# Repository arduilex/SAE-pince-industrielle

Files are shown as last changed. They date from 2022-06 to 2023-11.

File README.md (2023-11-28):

# SAE-pince-industrielle
Instrumentation d'une pince pour un robot indutrielle Stäubli avec retour d'information sur l'état de la pince sur une IHM.

Vous pouvez lire le [Rapport](ressources/Rapport.pdf) et le [mannuel d'utilisation](ressources/manuel_utilisateur.pdf)

Ce projet a été réalisé dans le cadre d'une SAE de mon BUT GEII en première année à l'IUT de Mulhouse.

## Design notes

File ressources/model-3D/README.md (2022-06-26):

Ce dossier contient :
- le boitier, qui contient la Raspberry Pi et ses extensions (pifacecad)
- le couvercle, pour fermé le boitier 
- les boutons, qu'il faudra placer sur les 5 trous du boitier avant de poser le pifacecad

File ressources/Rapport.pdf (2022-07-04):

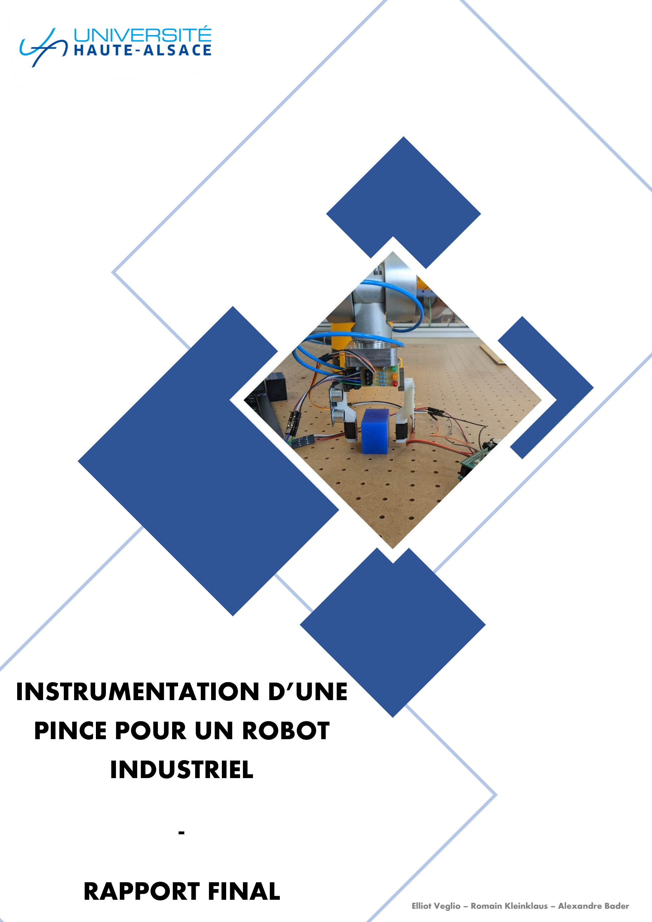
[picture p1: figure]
INSTRUMENTATION D’UNE PINCE POUR UN ROBOT INDUSTRIEL; RAPPORT FINAL

Elliot Veglio – Romain Kleinklaus – Alexandre Bader

Sommaire

### Présentation rapide de la SAE

### Contexte de la SAE

Sur un robot indus triel, la pince est un des dispositifs qui permet au robot d’interagir avec son

environnement. Grâce à une pince, le robot peut par exemple ramasser, tenir ou déplacer des objets.

Sur les robots industriels présents à l’IUT, la pince est commandée par le robot, mais il n’y a pas de

retour d’information quant à la saisie et aux collisions.

### But du travail

En tant qu’étudiant, notre but était donc d’instrumenter ces pinces pour avoir d’une part un retour sur

la saisie d’un objet et d’autre part pour détecter une collision de la pince avec un objet environnant.

Le but étant de récupérer le retour en temps réel pour améliorer la robustesse du système.

### Planning

### Planning & diagramme de Gantt théorique

Nous avons, au début de notre projet, mis en place un planning théorique que nous avons essayé de

respecter.

Nous avons retenu 11 étapes :

1. Synthèse capteurs
2. Mesures sur tables pour le capteur HC
3. Design mors
4. Tests des mors
5. Intégration sur la pince pour le capteur HC
6. Rapport de projet pour le capteur HC
7. Présentation orale pour le capteur HC
8. Mesures sur table pour le capteur ToF
9. Intégration sur la pince pour le capteur ToF
10. Rapport final du projet
11. Présentation orale finale

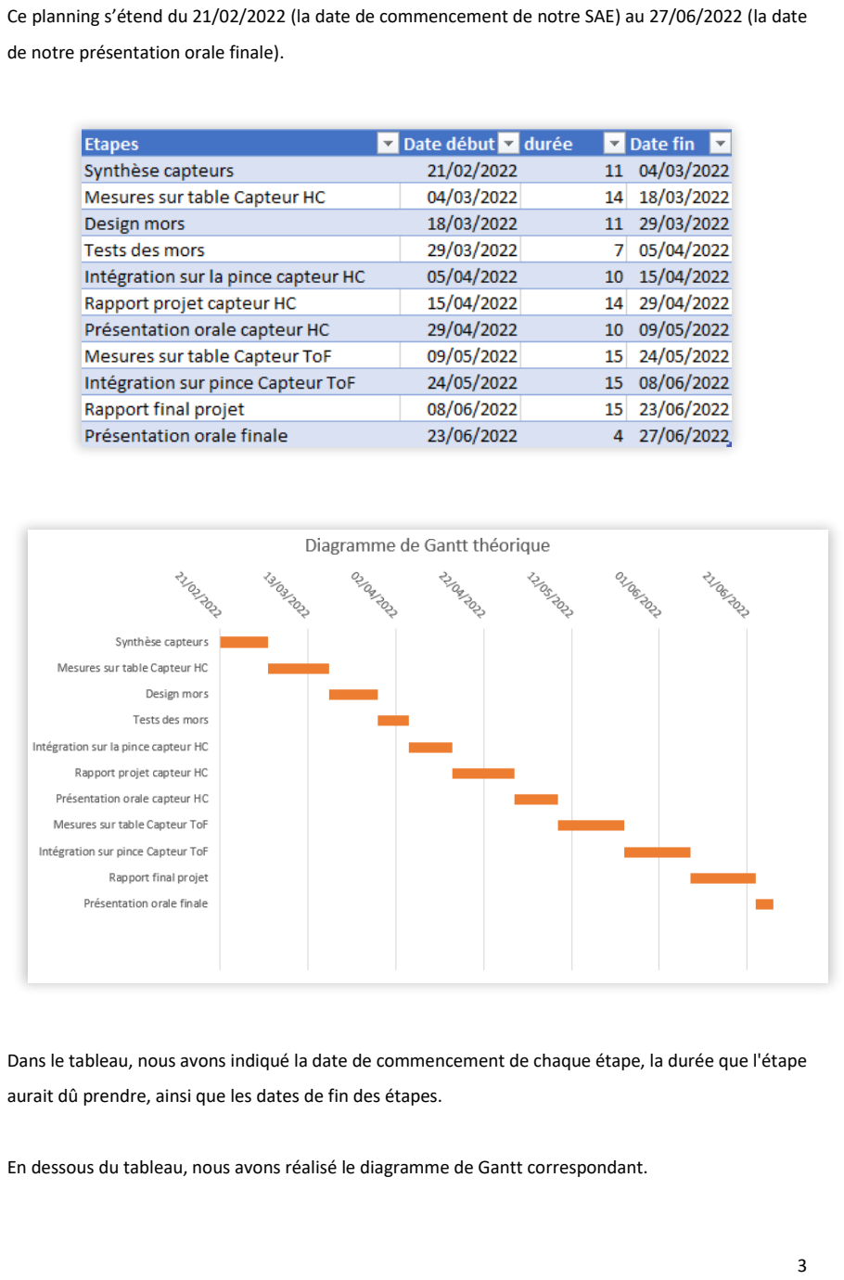
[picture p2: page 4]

Ce planning s’étend du 21/02/2022 (la date de commencement de notre SAE) au 27/06/2022 (la date

de notre présentation orale finale).

Dans le tableau, nous avons indiqué la date de commencement de chaque étape, la durée que l'étape

aurait dû prendre, ainsi que les dates de fin des étapes.

En dessous du tableau, nous avons réalisé le diagramme de Gantt correspondant.

### Planning & diagramme de Gantt réel

Au cours de la réalisation de notre projet, nous n’avons pas pu respecter complètement le planning

théorique annoncé.

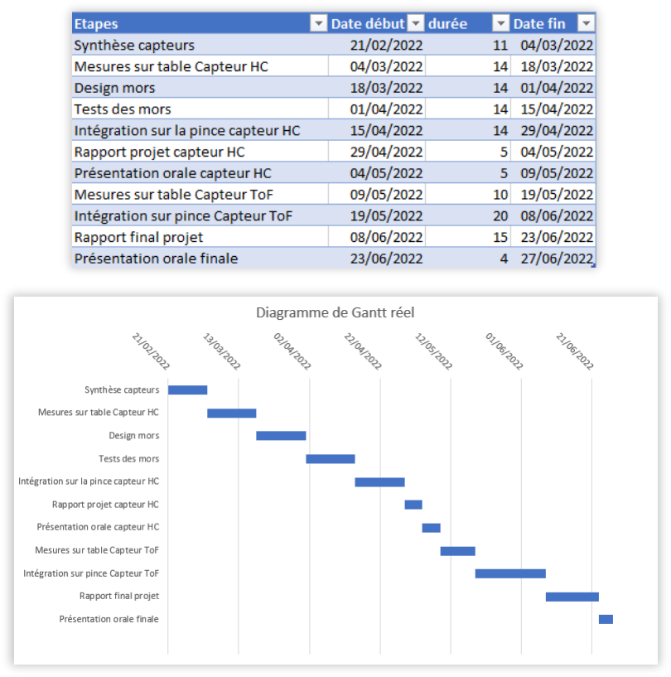
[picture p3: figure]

Nous constatons que certaines durées sont plus ou moins différentes selon les étapes dans le tableau

ci-dessus, si on les compare aux durées du tableau du planning théorique.

On remarque, entre autres, que nous avons passé deux fois moins de temps que prévu à travailler sur

le rapport de projet du capteur à ultrason et sur sa présentation orale.

### Répartition des tâches

Pour réaliser ce projet, nous nous sommes réparti les tâches à réaliser dans le but de travailler plus

efficacement.

Alexandre a travaillé principalement sur la partie programmation de notre projet, il a réalisé une

grande partie des programmes que nous utilisons.

Elliot et Romain se sont plus concentrés sur la conception des mors, du PCB et de l’intégration du

système sur la pince. Ils ont également réalisé les mesures sur table et le test des mors sur la pince

avec l’aide d’Alexandre.

Pour la réalisation de la synthèse sur les capteurs, des rapports et des présentations orales, nous avons

également travaillé à 3.

### Analyse critique de nos travaux

### Synthèse sur l’étude des capteurs

Pour avoir un retour d’information concernant la saisie ou les collisions, nous avions à disposition

plusieurs capteurs :

- Le capteur Capacitif CR30S
- Le capteur Ultrason HC-SR04
- Le capteur Photoélectrique VTF 180-2N4111
- Le capteur Laser ToF VL53L0X

Nous avons donc étudié ces 4 capteurs pour en savoir plus sur leur mode de fonctionnement et pour

apprendre à les différencier. Pour chacun d’entre eux, nous avons dû expliquer dans un rapport de

synthèse :

- Principe de fonctionnement
- Gamme de mesure, précision, fréquence
- Identifier le type de sortie
- Comment était-il alimenté et comment communiquer avec lui

- Enfin, quels choix étaient les plus optimaux pour l’intégrer sur la pince

Nous allons donc vous parler de ce que nous avons retenu de cette étude.

Concernant le capteur laser ToF, celui-ci peut être alimenté sous une tension comprise entre de 2.6V

et 3.5V ce qui est compatible avec les GPIO de la Raspberry Pi de 3.3V. Il peut ainsi être commandé et

branché directement depuis la Raspberry Pi, ce qui facilite grandement son installation sur la pince. De

plus, sa gamme de mesure est cohérente avec les distances que nous voulons mesurer. Ce capteur

peut donc être utilisé dans le cadre de l’instrumentalisation d’une pince industrielle.

Le capteur capacitif CR30S peut être utilisé pour s’arrêter avec une grande fiabilité devant un objet, ou

encore d’envoyer un signal de confirmation de fermeture de la pince. Malheureusement, sa tension

d’alimentation étant supérieur à 10V, son utilisation sur Raspberry pi n’est pas possible sans l’aide

d’une alimentation externe supplémentaire, car le Raspberry ne peut fournir que 5V au maximum.

Le capteur à ultrasons HC-SR04 est un capteur très polyvalent, sa petite taille, sa gamme de mesure

large qui reste précise de 3cm à 400cm, sa facilité d’utilisation et sa tension d’utilisation de 5V qui est

compatible avec la Raspberry Pi le rend très adapté dans le cadre de notre SAE.

Le capteur Photoélectrique VTF 180-2N41112, pourrait être utilisé avec nos mors afin de détecter la

présence des pièces près de la pince pour faciliter la manipulation de la pince ou encore éviter les

collisions. Cependant, la tension d’alimentation de ce capteur, qui est de 10V DC à 30V DC est trop

grande pour pouvoir être exploitée avec un Raspberry Pi sans l’aide d’une alimentation externe, car

ses pins ne délivrent qu’une tension de 3,3V ou 5V maximum.

Conclusion :

Parmi tous les capteurs que nous avons étudiés, le capteur laser ToF VL53L0X ainsi que le capteur à

ultrasons HC-SR04 sont, selon nous, les plus faciles et pratiques à utiliser avec un Raspberry Pi. Il n’est

cependant pas impossible d’utiliser les autres capteurs, à condition d’utiliser une alimentation externe

pour compenser la limite de 5V délivrés par la Raspberry Pi.

### Mesures sur table

Nous avons tout d’abord effectué plusieurs mesures de distances sur table, avec différents types

d’objets, pour tester les limites réelles du capteur. Ces tests ont pour but d’évaluer la précision de nos

mesures en fonction de différentes conditions. Pour mieux présenter nos résultats, nous avons classé

nos mesures en fonction des critères suivants :

- La matière de l’objet
- La couleur de l’objet
- L’orientation de l’objet
- La taille de l’objet

La matière de l’objet

Pour déterminer si la matière de l’objet a un impact sur la précision de nos mesures, nous avons décidé

de prendre plusieurs objets avec des matières différentes, à savoir : du plastique, du carton, du métal,

du plexiglas et du verre. Nous avons ensuite fait une série de mesures sur plusieurs distances.

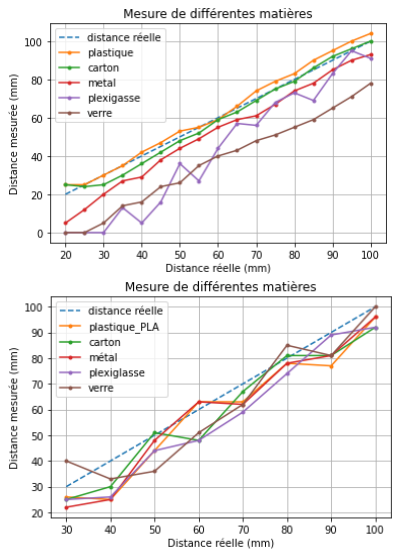
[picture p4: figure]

Voici les résultats que nous avons obtenus :

Capteur laser

Capteur à

ultrasons

Si l'on observe le graph du capteur laser, on s'aperçoit que les matières qui diffractent la lumière ou

laissent passer la lumière (le verre et le plexiglas) ont tendance à s'éloigner de la distance réelle. Tandis

que les matières qui diffusent la lumière, telles que le plastique ou le carton, sont plutôt proche de la

réalité.

On peut donc en conclure que le capteur laser est inutilisable sur des objets qui diffracte la lumière

tels que des objets en verre ou en plexiglas. Cela ne nous pose pas de problème, car notre capteur ToF

va être utilisé face à une surface en plastique PLA.

Concernant le capteur à ultrasons, on ne remarque pas de grandes différences entre les courbes, on

en déduit que la matière importe peu pour la qualité des mesures de ce capteur.

La couleur de l’objet

Pour déterminer si la couleur de l’objet avait un impact sur la précision de nos mesures, nous avons

décidé de prendre un Rubik’s Cube pour faire des mesures avec chacune de ses faces. Sachant que le

Rubik’s Cube est en plastique (l’une des matières les plus fidèles comme montré précédemment)

seules les différentes couleurs rentrent en jeu.

Voici les résultats que nous avons obtenus :

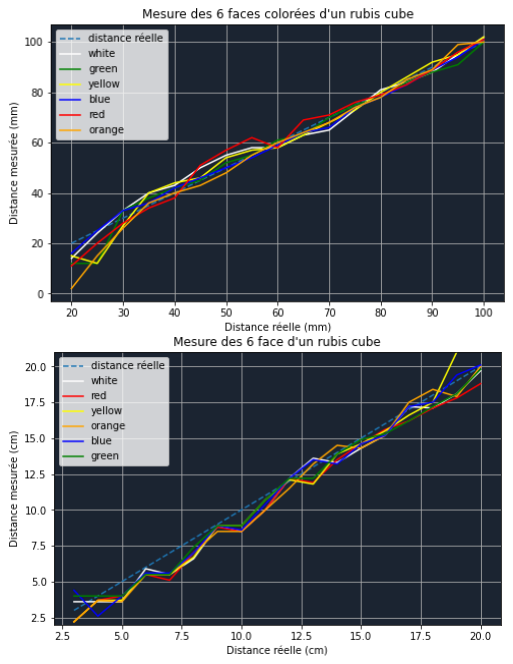
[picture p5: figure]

Capteur laser

Capteur à

ultrasons

D’après les graphes que nous avons obtenu pour le capteur laser et le capteur à ultrasons, on remarque

qu’il n’y a aucune une différence et qu’elles convergent toutes vers la distance réelle.

Ainsi, on peut dire que la couleur de l’objet n’influe pas sur la précision de nos mesures que ce soit

avec le capteur laser ou le capteur à ultrasons.

L’orientation de l’objet

Pour déterminer si l’orientation de l’objet a un impact sur la précision de nos mesures, nous avons

décidé de prendre une plaque en plastique pour faire des mesures en changeant l’orientation du

capteur en fonction de la plaque.

Voici les résultats que nous avons obtenus :

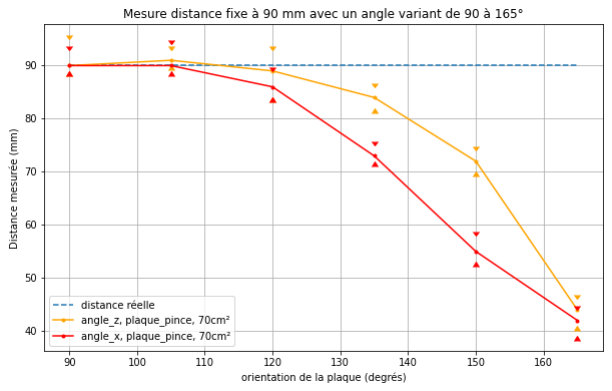
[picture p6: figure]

Capteur laser

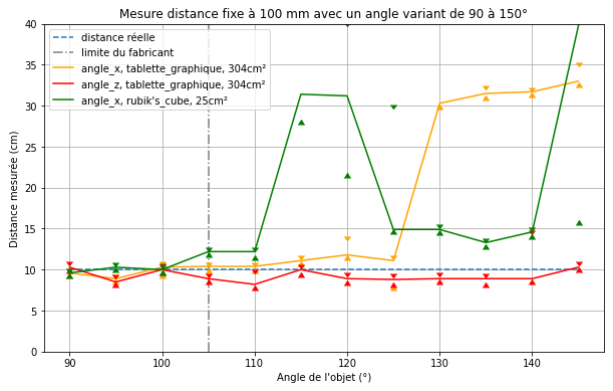
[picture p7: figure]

Capteur à

ultrasons

D’après le graphe que nous avons obtenu, on remarque que lorsqu’on modifie l’angle (que ce soit de

façon horizontale ou verticale), plus l’orientation de la plaque s’éloigne de 90 degrés, plus la distance mesurée est faussée. À partir de 110° les mesures sont inexploitables. Si l’on souhaite obtenir une

mesure précise, il faut que l’objet soit positionné de façon perpendiculaire par rapport au capteur

laser.

La taille de l’objet

Enfin, concernant la taille de l’objet, nous avons décidé de prendre une feuille, que nous avons pliée

en 2 entre chaque mesure. Ainsi, nous avons divisé par 2 la surface de la feuille (et donc la taille de

l’objet) pour chacune des mesures prises par le capteur

Voici les résultats que nous avons obtenus :

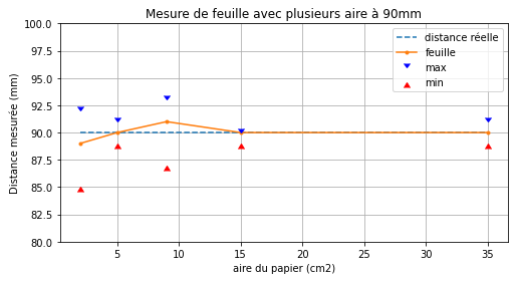
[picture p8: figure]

Le graphe que nous avons obtenu, représentant la mesure de la distance en fonction de la surface de

la feuille, est plus ou moins une droite. Ceci signifie que la taille d'un objet n'a pas d'incidence sur les

mesures que prend le capteur ToF.

Capteur laser

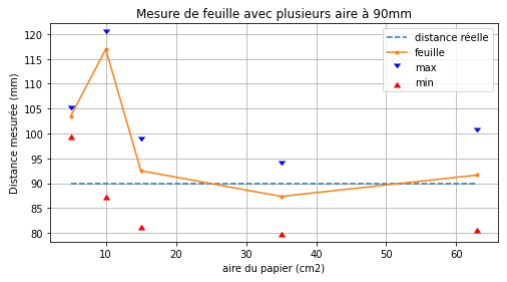
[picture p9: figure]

Capteur à

ultrason

Nous avions également fait les mêmes mesures avec le capteur HC, on constate toute de suite qu’avec

ce capteur, une surface trop petite à des conséquence néfaste sur la qualité de la mesure. A partir de

15cm² les mesures sont exploitables, mais pas en dessous.

### Réalisation des mors

Afin d’intégrer le capteur sur les mors il nous faut designer des mors compatible avec les 2 capteurs,

ce qui est réalisable, car les 2 capteurs ne demandent que 4 pins de connexion. L'emplacement des

pins va être utilisé comme support pour maintenir le capteur en place.

Pour concevoir les mors que nous devions intégrer sur la pince, nous avons utilisé le logiciel de

modélisation Autodesk Fusion 360.

Nous nous sommes basés sur ces dimensions imposées :

- Taille minimum entre les mors pince fermé de 2,5cm.
- Surface de contact avec les objets pour les mors (1,5*2cm).
- Taille minimum des câbles entre le Raspberry et la pince 30 cm.

Lors de la conception de nos mors, nous avons fait attention à bien réfléchir à l’intégration du capteur

sur ceux-ci. Nous avons décidé de fixer le capteur sur le haut du mors droit, et d’insérer une plaque sur

le mors gauche, le tout créé par une imprimante 3D. Puisque nous avons décidé d’implémenter le PCB

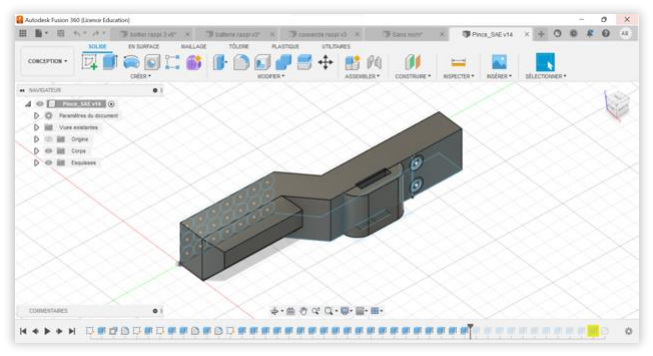
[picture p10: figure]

sur la pince, nous n’avons pas besoin de modifier nos mors pour y intégrer le PCB. Le principe de

fonctionnement est simple, le capteur à ultrasons ou laser va envoyer des ondes sonores ou

électromagnétiques en direction de la plaque en plastique. Les ondes vont rebondir sur cette dernière

pour ensuite se propager dans la direction inverse, vers le capteur. Le temps de vol de l’onde entre son

émission et sa réception est utilisé pour calculer la distance entre le capteur et la plaque.

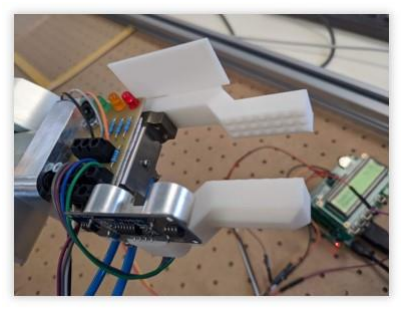
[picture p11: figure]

Réalisation du PCB.

Nous avons également réalisé un PCB sur Kiccad pour notre système. Ce PCB permet de réaliser la

liaison électrique entre le capteur et le Raspberry Pi. Nous avons placé des borniers pour les liaisons

électriques, des résistances et il y a également 3 LEDs rouge, orange et verte respectivement qui

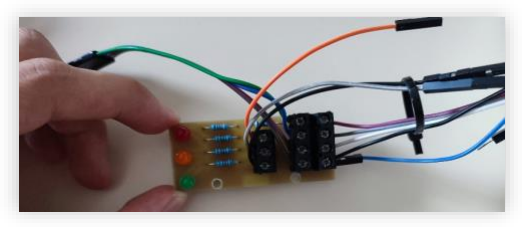
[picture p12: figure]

permettent d’indiquer l’état de la pince.

Notre PCB est assez petit, car nous l’intégrons sur la

pince directement et la place disponible est limitée.

### Réalisation du boîtier

Le boîtier permet de protéger le circuit de la Raspberry Pi et ses modules de l’extérieur. Le but étant

de pouvoir fixer le boîtier sur le bras du robot et ainsi limiter au maximum les longs câbles qui

parcourent le bras robotique pour arriver sur la table, car cela peut limiter les mouvements du robot.

Construction

La base du boitier doit pouvoir maintenir fermement la Raspberry Pi. Pour cela, nous utilisons les 4

trous disponibles sur cette dernière. On trouve facilement sur internet les dimensions précises de la

Raspberry Pi, ainsi la modélisation correspond parfaitement à la réalité. Pour se fixer sur ces trous,

nous utilisons 4 trous taraudés pouvant accueillir une vis M2.5.

Un trou est placé sur le bas-côté pour faire entrer le câble micro USB d’alimentation.

Le couvercle du boitier est imprimé à part. Il comporte 2 rectangles vide : l’un pour faire ressortir

l’écran LCD, l’autre pour sortir les 12 câbles de breadboard connecté à la Raspberry Pi.

Pour maintenir ces câbles, nous utilisons de la colle chaude.

Sur 2 faces du boitier, 9 trous ont été ajouter afin de créer une ventilation, indispensable pour le micro-

ordinateur qui dégage une chaleur non négligeable.

Pour alimenter la Raspberry Pi tout en restant indépendant du réseau électrique sur secteur, nous

avons opté pour une batterie externe de 20 000 mAh ainsi qu’un câble micro USB coudé de 25cm pour

une meilleure ergonomie.

Problèmes rencontrés

Le bouton/joystick est très ergonomique à utiliser, nous avons essayé de l’utiliser avec le boitier, mais

malheureusement il est très difficile à utiliser une fois dans le boitier, alors que les boutons ont juste

besoin d’une rallonge. Nous avons donc abandonné le bouton/joystick pour se concentrer sur les 5

boutons de l’avant.

Les encoches du couvercle nous ont posé beaucoup de problèmes. En effet, ils doivent être

parfaitement identique aux encoches femelles du boitier, mais avec une échelle inférieure de l’ordre

du 10ᵉ de millimètre pour pouvoir s’emboiter.

L’emplacement des trous sur le boitier pour communiquer avec les boutons nous a valu plusieurs ratés

de positionnement. Nous ne pouvions pas mesurer avec précision à quelles hauteurs ils étaient placés,

car la structure des 2 modules n’est pas fixe. De plus, toute la modélisation devait avoir comme

référence les 4 trous de fixation de la Raspberry Pi.

Boitier dans sa version finale contenant la Raspberry Pi et ses modules

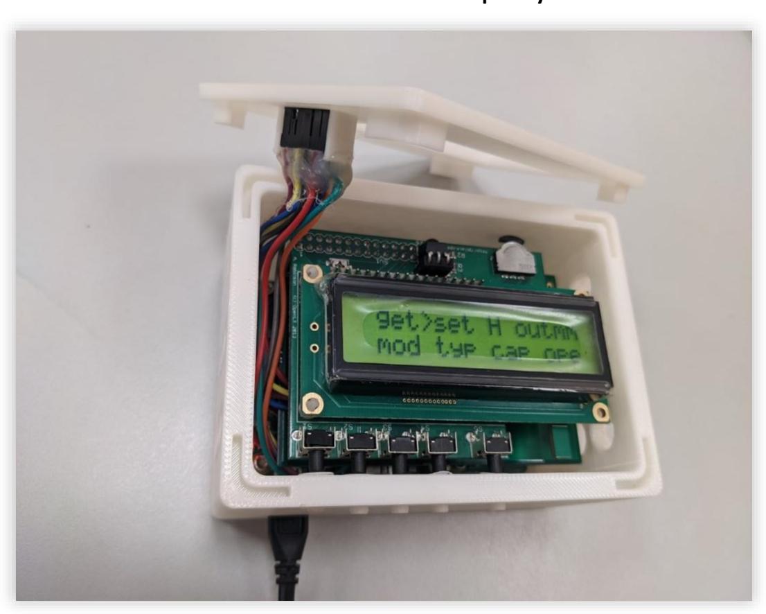
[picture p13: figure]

### Réalisation Programme

L’entièreté du programme à été développé en Python 3.9. Le programme principale (voir annexe)

repose sur des fonctions asynchrones. Elles permettent de s’exécuter en même temps, par

concurrence, c’est-à-dire lorsque qu’une fonction ne fait rien (pause await) une autre s’exécute.

Toutes ces fonctions en concurrence vont appeler des fonctions qui se trouve dans un autre fichier :

appli.py. Ce fichier contient une classe Python qui gère l’entièreté de l’interface et du système de

mesure. Le principe de classe est indispensable ici car il permet de se passer des variables globales en

utilisant self (un objet contenant toutes les variables et fonctions créés dans la classe) dans chaque

paramètre de fonction (appelé méthode dans une classe).

Sur la partie appli.py on peut voir le fonctionnement de la méthode d’initialisation, elle va rechercher

des fichiers texte qui contiennent des valeurs sauvegarder de la dernière exécution du programme. La détection de l’état de la pince se fait en fonction de la distance mesurer par le capteur. Cette mesure

est appelée via une fonction qui se trouve dans un autre fichier. Soit le programme va accéder au

fichier HCS404.py si le capteur utilisé est l’ultrason, soit dans le fichier VL53L0X.py si le capteur utilisé

est le laser.

Nous avons rencontré beaucoup de problème au cours du développement, notamment sur les

fonctions asynchrones et les classes qui étaient des nouvelles notions à assimilé pour nous. Alexandre

nous à beaucoup aidé grâce à ses connaissances avancées dans le langage Python.

### Intégration du système sur la pince

Après avoir conçu notre système, nous allons maintenant parler de l’intégration de celui-ci sur la pince.

Tout d’abord, pour intégrer les 2 mors imprimés en 3D sur la pince, nous avons utilisé les 4 trous

taraudés de chaque côté de la pince pour les fixer sur celle-ci.

Nous avons également réalisé le circuit électrique comprenant la Raspberry Pi, son alimentation, un

optocoupleur et le capteur.

Grâce à l’aide d’un optocoupleur, nous pouvons envoyer un signal de 24V aux entrées TOR, à l’aide du

signal sortant de la Raspberry Pi de 3.3V.

L’optocoupleur peut rendre des circuits électriques indépendants. En effet, l’optocoupleur est un

composant électronique permettant de transmettre un signal d’un circuit électrique à un autre sans

être relié électriquement avec lui permettant de garantir l’isolation galvanique. Il est formé d’une LED

infrarouge et d’un phototransistor.

Lorsqu’un courant électrique passe dans la LED, elle va émettre un signal infrarouge dans un boîtier

hermétique à la lumière. Le phototransistor va ensuite capter la lumière infrarouge et devenir passant

pour transmettre le courant électrique.

Ci-dessous le résultat final de notre système fonctionnel. Une batterie externe de 20000mAh est placée

sous le boitier

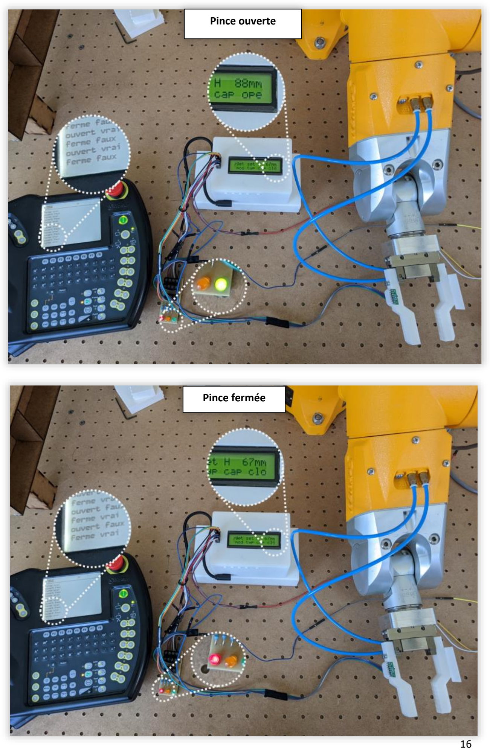
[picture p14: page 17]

Pince ouverte

Pince fermée

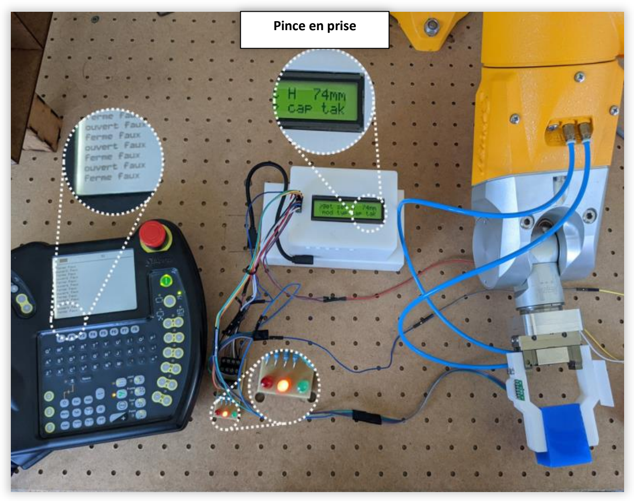
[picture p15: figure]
Pince en prise

Lors de nos tests en condition réels sur le bras robotique, nous pouvions choisir la précision du capteur

ToF, il en possède 4 : speed, good, better et best. Le mode speed est le moins précis des 4, mais à

l’inverse du mode best, il est le plus rapide avec un taux de rafraîchissement de 50 mesures / seconde

contre 30/s en good, 15/s en better et 5/s en best.

Tous ces modes sont implémentés dans le module open source du capteur ToF que nous avons

récupéré sur GitHub. (https://github.com/pimoroni/VL53L0X-python) Pour avoir une similarité avec le capteur ultrason, nous avons créé une classe

Python qui possède la même gestion de ces 4 modes.

Pour revenir à nos tests réels, il est clair qu’en choisissant le mode best, on obtient de meilleurs

résultats dans le maintien d’un état détecter de la pince au cours du temps. Si on passe à des modes

moins précis, il en résulte des fluctuations de l’état (par exemple la pince est ouverte et l’état retranscrit varie entre ouvert et en prise). Pour essayer de comprendre pourquoi ce phénomène ce

produit, nous avons réalisé des mesures semblables à un oscillogramme.

La courbe bleue représente les mesures du capteur au cours du temps, en orange la courbe est la

retranscription de l’état de la pince au cours du temps. Les 3 états sont facilement lisibles : ouvert =

85mm, en prise=79mm, fermé=74mm.

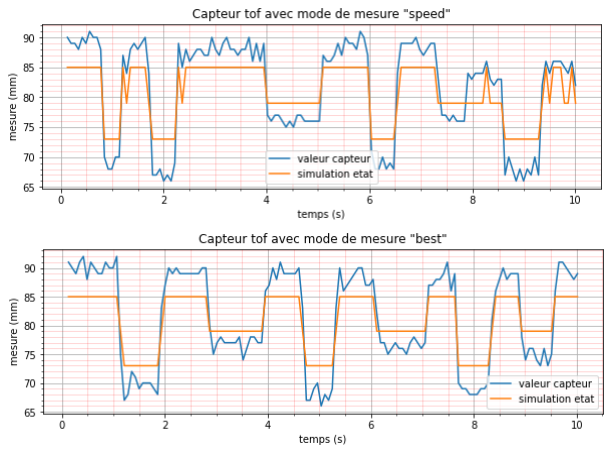
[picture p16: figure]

On remarque tout de suite que pour le même réglage des valeurs limite, le mode best est beaucoup

plus précis et comporte moins d’erreur. Le même phénomène se produit avec le capteur ultrason.

Comme nous l’avons vu le mode best comporte moins d’erreur, mais il permet que de fournir 5

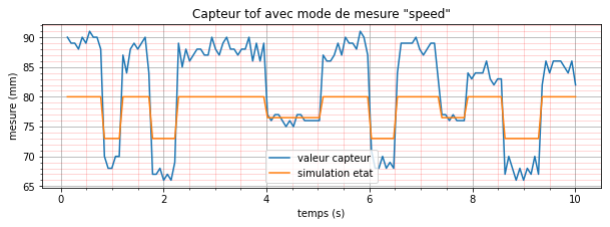
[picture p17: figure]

mesures par secondes. La première solution qui vient à l’esprit serait d’utiliser un compromis entre

speed et best comme good ou better, mais il existe une 2eme solution qui consiste à modifier les

valeurs limites d’état.

En changeant la valeur max de 85mm à 80mm, on obtient un signal aussi propre que celui du mode

best. Ainsi, nous pouvons allier la haute fréquence de mesure de ce mode sans obtenir d’erreur.

Néanmoins, une nouvelle contrainte est créée : l’état en prise, devient très serré entre le max et le

min. Les objets pris par la pince doivent alors obligatoirement être d’une taille proche de 77mm.

On peut donc définir le théorème suivant : plus les valeurs limites d’états sont éloignées, plus la taille

de l’objet entre les mors peut varier. La réciproque est aussi vraie.

### Synthèse

Au cours de cette année, nous avons appris à instrumentaliser une pince pour améliorer sa robustesse.

L’amélioration majeure apportée est un retour d’information sur l’état de la pince via un capteur de

distance. Le retour d’information se faisant au travers de 3 LEDs, de l’écran LCD mais aussi sur la

télécommande du robot. Pour intégrer le capteur, nous avons créé une nouvelle version des mors.

Nous avons découvert, pour certain, la modélisation 3D ainsi que l’impression 3D. Le système est

embarqué via un Raspberry Pi et le module PifaceCad comportant un écran LCD et des boutons. Nous

avons appris à nous servir de Linux et enrichi nos connaissances en Python.

Nous avons réalisé le projet sur une période de 126 jours et nous avons pu respecter les délais pour

chaque tâche demandée.

Tableau des coûts du projet :

Objet | Coût
Raspberry Pi + PifaceCad | 56,88€ (TTC)
Composants électronique (LED, résistances, borniers, câbles) | 3,00€ (TTC)
Capteur ToF | 16,00€ (TTC)
Capteur HC | 5,00€ (TTC)
Plastique imprimante 3D | 10,00€ (TTC)

Outils (pince coupante, tournevis, etc…) | 20,00€ (TTC)
TOTAL : | 110,88€ (TTC)

### Perspective pour les suites éventuelles

Après la réalisation de ce projet, notre système permet l’instrumentalisation d’une pince, ce qui nous

ouvre la voie à de nombreuses perspectives.

Tout d’abord, on pourrait améliorer la stabilité du capteur sur les mors, ainsi que celle de la plaque

fixée sur un des mors pour ainsi améliorer l’exactitude des mesures et du retour d’information

concernant la prise d’objet. On envisagerait également d’améliorer le circuit électrique reliant le

système, en implémentant, entre autres, l’optocoupleur dans le circuit et en travaillant sur la gestion

des câbles pour obtenir un système plus compact et mieux rangé.

En effet, ce système pourra améliorer la prise d’objet de la pince, tout en implémentant une détection

de collisions.

Du fait de cette instrumentalisation de la pince, on peut imaginer que l’on pourra plus facilement

résoudre certains problèmes, dont celui des Tours d'Hanoï, qui requiert une précision accrue de la

prise d’objet faite par la pince.

On pourra également espérer créer l’automatisation de certaines tâches grâce au système à l’aide de

la création de programmes supplémentaires.

### Annexes

Organigramme de l’application en Python :

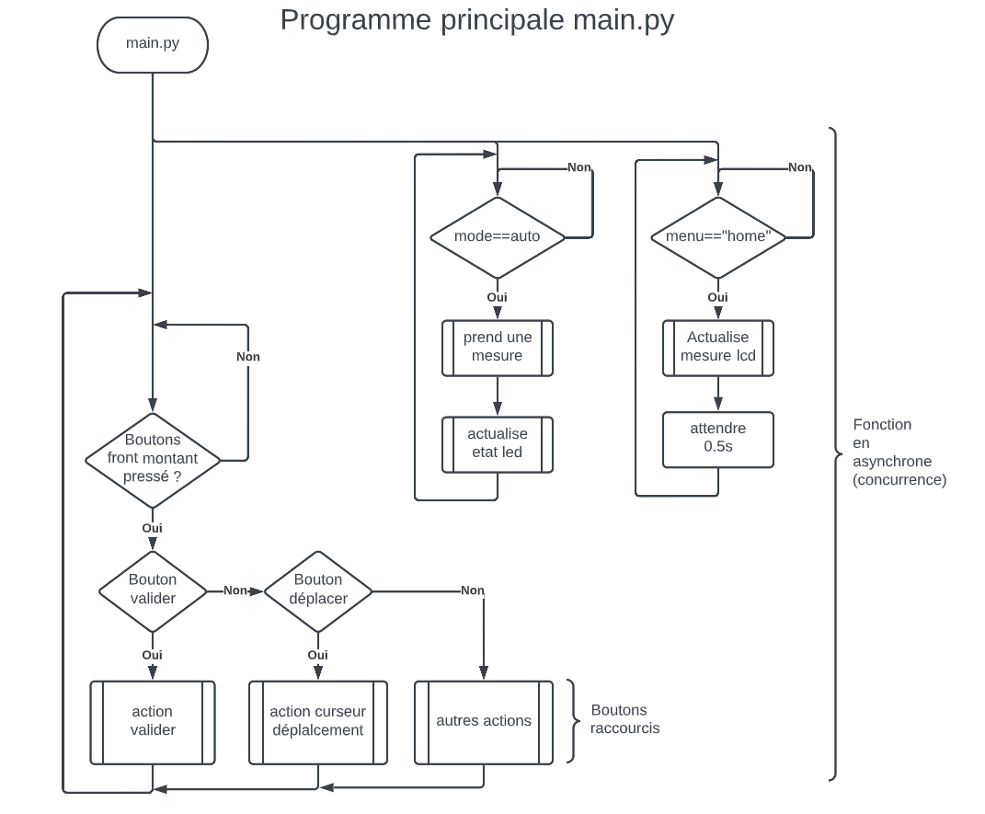
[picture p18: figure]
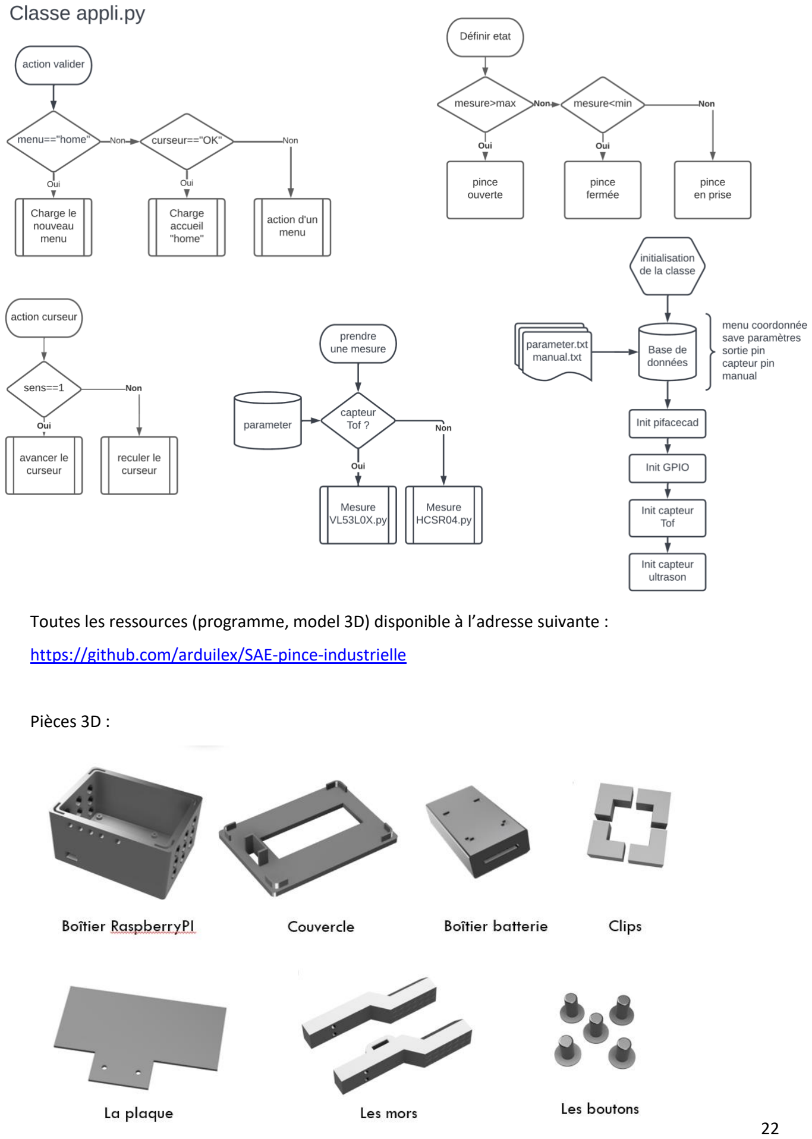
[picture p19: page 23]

Toutes les ressources (programme, model 3D) disponible à l’adresse suivante :

https://github.com/arduilex/SAE-pince-industrielle

Pièces 3D :

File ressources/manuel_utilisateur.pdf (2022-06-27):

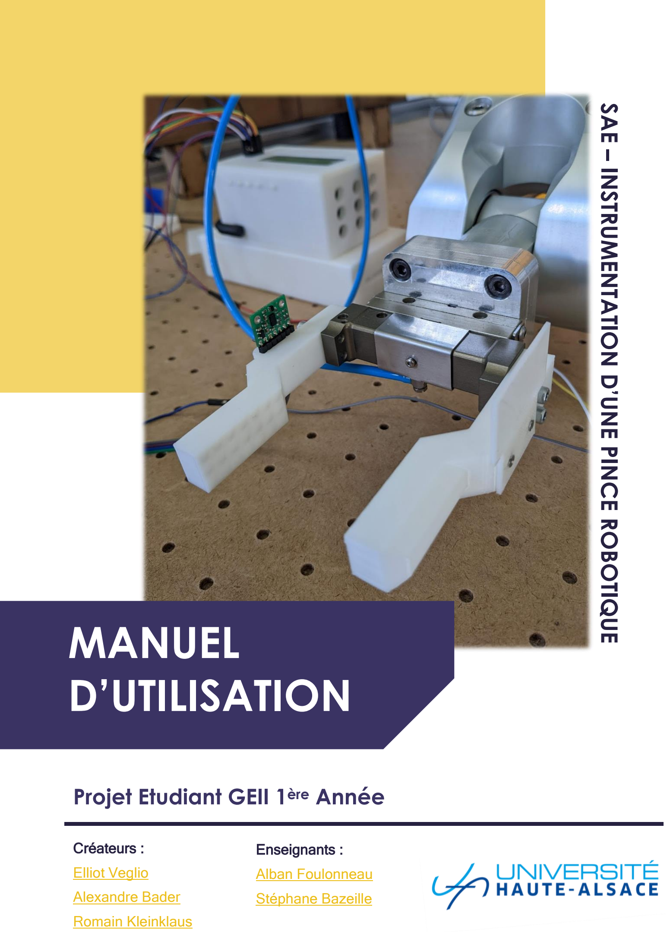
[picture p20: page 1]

# MANUEL D’UTILISATION

## Projet Etudiant GEII 1

è
r

e

## Année

Enseignants :

Alban Foulonneau

Stéphane Bazeille

Créateurs :

Elliot Veglio

Alexandre Bader

Romain Kleinklaus

## SAE – INSTRUMENTATION D’UNE PINCE ROBOTIQUE

2

# TABLE DES MATIÈRES

AVANT DE COMMENCER ______________________________________________________________ 3

Introduction ____________________________________________________________________________________3

Composants prérequis ___________________________________________________________________________3

Consigne de sécurité ____________________________________________________________________________4

IMPRESSION 3D _____________________________________________________________________ 4

1. Le boitier__________________________________________________________________________________4
2. Le couvercle_______________________________________________________________________________5
3. Boitier batterie _____________________________________________________________________________5
4. Clips _____________________________________________________________________________________5
5. Boutons __________________________________________________________________________________5
6. Les mors__________________________________________________________________________________6
7. La plaque _________________________________________________________________________________6

CONFIGURATION DE LA RASPBERRY PI_________________________________________________ 6

Activation I2C __________________________________________________________________________________6

Installation de l’application ________________________________________________________________________7

Installation module Tof ___________________________________________________________________________7

Se connecter en SSH ____________________________________________________________________________8

ASSEMBLAGE _______________________________________________________________________ 9

Etape 1 : Préparation du Raspi ____________________________________________________________________9

Etape 2 : Fixation Raspi __________________________________________________________________________9

Etape 3 : Soudure du SparqEE ___________________________________________________________________10

Etape 4 : Connexion GPIO_______________________________________________________________________10

Etape 5 : Fixation SparqEE ______________________________________________________________________11

Etape 6 : Pose boutons _________________________________________________________________________11

Etape 7 : Fixation Pifacecad______________________________________________________________________11

Etape 8 : Placement câbles ______________________________________________________________________12

Etape 9 : Coller câble ___________________________________________________________________________12

Etape 10 : Fixation clips _________________________________________________________________________13

Etape 11 : Liaison câble _________________________________________________________________________13

Etape 13 : Fixation plaque _______________________________________________________________________15

Etape 12 : Fixation mors_________________________________________________________________________15

UTILISATION DE L’INTERFACE ________________________________________________________ 15

Lancement de l’application_______________________________________________________________________15

Prendre une mesure (get) _______________________________________________________________________16

Définir limite état (set)___________________________________________________________________________16

Mode de mesure (mod) _________________________________________________________________________17

Type de précision (typ) __________________________________________________________________________17

Changer de capteur (cap)________________________________________________________________________18

Menu Help (H)_________________________________________________________________________________18

FOIRE AUX QUESTIONS______________________________________________________________ 19

3

# AVANT DE COMMENCER

Introduction

Ce projet a été réalisé par un groupe de la promo 2021-2022 des GEII. Le but du projet est

d’instrumentaliser une pince pour avoir run retour d’information sur la saisie d’objet. Cette

pince est actionnée par un bras robotique Stäubli TX40 qui se trouve dans la salle

d’automatisme du bâtiment B. L’ouverture et la fermeture des mors de la pince s’effectue

grâce à de l’air comprimé. La commande de cette action se fait via la télécommande du

robot, sur un bouton.

Le problème est que si l’on programme ce robot pour réaliser des déplacements d’objets,

le robot ne peux pas confirmer s’il est en saisie d’objet. Or grâce à ce projet, notre système

va pouvoir envoyer un signal d’état instantané de la pince (fermé, ouvert, en prise) au

programme du robot. L’état de la pince est déduit par les mesures d’un capteur de distance.

L’état est ensuite chiffré en 2 signaux électrique 24V qui sont envoyé au robot. Le tout est

contrôlé par un Raspberry Pi encastré dans un boitier imprimé en 3D.

Composants prérequis

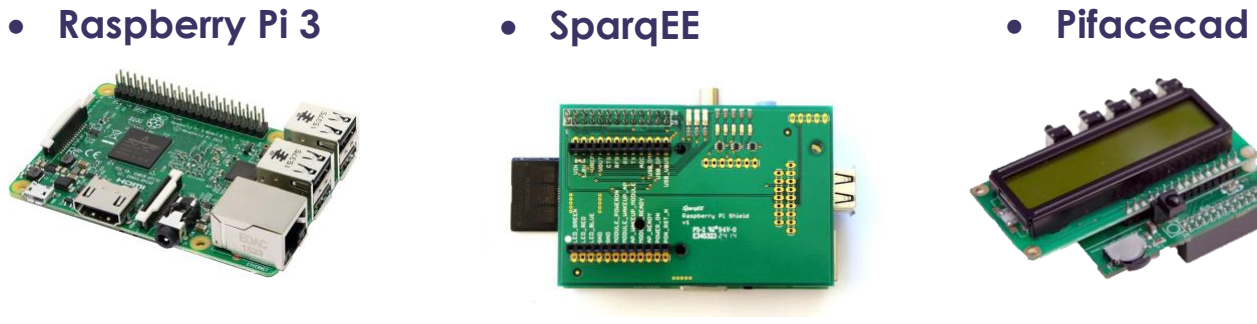
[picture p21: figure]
• Raspberry Pi 3; • Pifacecad; • SparqEE
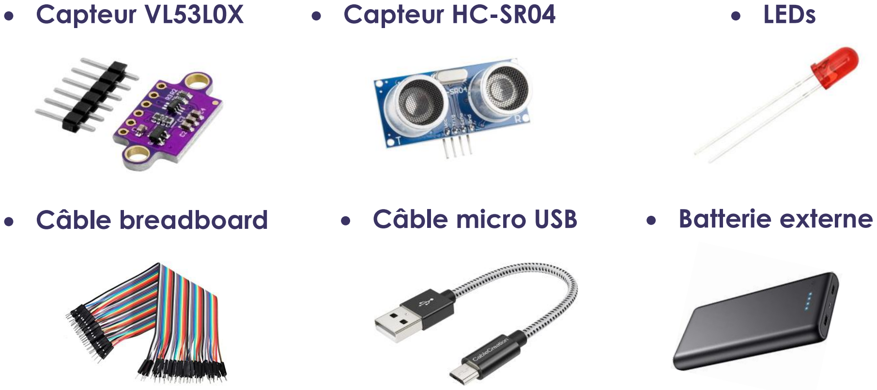
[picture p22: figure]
• Câble breadboard; • Batterie externe; • Câble micro USB

Vous pourrez vous fournir ces composant en passant commande à l’IUT Lab par exemple.

Nous ne parlerons pas de la réalisation du PCB dans ce manuel. Vous trouverez et

- Capteur VL53L0X | • Capteur HC-SR04 | • LEDs

4

apprendrez tout ce qu’il vous faut dans la salle de SAE du bâtiment B, les schémas

électriques nécessaire à la réalisation du PCB sont sur le GitHub. Le boitier de la batterie

externe a été modélisé pour la Power Bank 2C. (https://www.powerplanetonline.com/fr/xiaomi_mi_power_bank_2c_mah_20000) Vous devrez modifier les dimensions du

boitier pour votre batterie externe. Pour alimenter la Raspberry Pi via la batterie, vous

pouvez utiliser un simple câble micro USB ou coudé pour plus d’ergonomie.

Consigne de sécurité

- L’utilisation du robot peut être dangereuse sans le respect des consignes de sécurité,

demander impérativement à un professeur l’accès au robot pour qu’il vous explique

son fonctionnement.

- Lors de la construction du système, veuillez bien respecter puis vérifier le bon

branchement des câbles. Le non-respect de ces branchements peut au mieux

provoquer des disfonctionnements, au pire engendrer des cours circuit qui

endommagerons définitivement la Raspberry Pi.

# IMPRESSION 3D

Les modèles 3D ont été réalisés sur Fusion 360 que vous pouvez facilement installer

gratuitement (https://accounts.autodesk.com/register?viewmode=iframe&uitype=education) si vous êtes étudiant. Pour vous procurez ces modèles 3D rendez-vous sur le

GitHub (https://github.com/arduilex/SAE-pince-industrielle/tree/dev/ressources/model-3D) du projet ou en suivant ce lien : https://bit.ly/3bsh5RM

Vous pouvez utiliser les imprimantes 3D de l’IUT Lab mis à votre disposition. Le temps total

d’impression est d’environ 20h. Passons-en revu les 6 impressions à réaliser.

### 1. Le boitier

Sa base est composée de 4 trous de

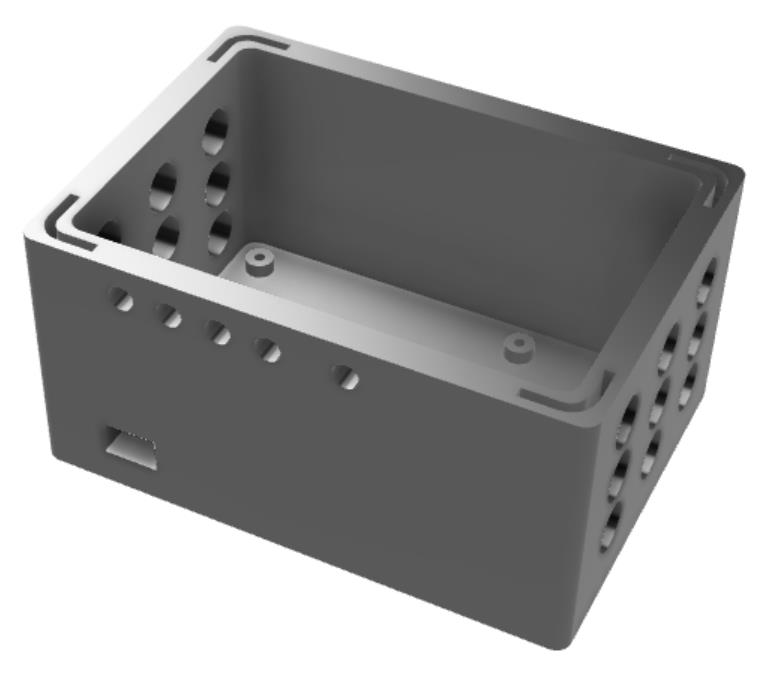
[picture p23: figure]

diamètre 2.5mm, ils servent à fixer la

Raspberry Pi. En bas à gauche un trou

rectangulaire va venir accueillir le câble

d’alimentation. Les 5 petit trous à l’avant

vont servir à interagir avec les boutons

du Pifacecad. Les 9 trous de chaque côté

ont comme objectif de ventiler le boitier

et refroidir la Raspberry Pi. Les encoche

du haut permettent le maintien du

couvercle. En dessous se trouve 4

encoches | supplémentaires | pour

s’accrocher au boitier de la batterie

externe.

5

### 2. Le couvercle

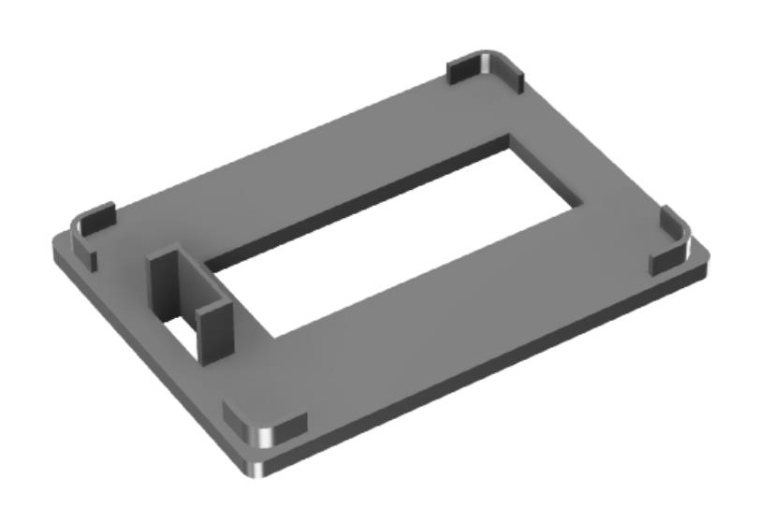
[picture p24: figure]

Il est composé de 4 encoches qui vont

venir s’emboiter avec le boitier. Le grand

trou vide rectangulaire centrale va faire

ressortir l’écran LCD du Pifacecad. Le

trou juste à côté ressort tous les câbles

de connexion entre le système extérieur

(robot, capteur, led) et le système

intérieur (Raspberry Pi).

3. Boitier batterie; 4. Clips

Sur le dessus se trouve 4 encoches pour le boitier

de la Raspberry Pi. A l’arrière, une fente de

sécurité permet de retirer la batterie dans le cas où

elle venait à se coincer dans le boitier. L’avant, non

visible ici, est pleinement ouvert pour venir

accueillir la batterie.

Ils maintiennent le boitier de la Raspberry Pi et le boitier de la

batterie externe ensemble.

### 5. Boutons

Ces 5 boutons sont des rallonges pour interagir avec les

boutons du Pifacecad. Sans eux, les boutons du Pifacecad

serait inaccessible dans le boitier depuis l’extérieur.

6

### 6. Les mors

Les 2 mors formes une paire. Celui de droite

comporte un trou pour fixer le capteur

dessus, plus précisément, le trou va

contenir les câble breadboard connecter au

capteur, ces derniers vont ressortir par le

dessous. Derrière le mors de gauche se

trouve 2 petit trou de 2mm pour maintenir la

plaque de mesure pour le capteur.


### 7. La plaque

# CONFIGURATION DE LA RASPBERRY PI

Avant d’assembler les cartes électroniques dans le boitier, il nous faut configurer la

Raspberry Pi tant que ses ports USB et HDMI sont accessible. Si la Raspberry Pi ne

démarre pas, chercher un tuto sur comment installer Linux sur une Raspberry Pi. (https://raspberry-pi.fr/creez-carte-sd-raspbian-raspberry-pi-windows/) Une fois

dans le boitier il faudra communiquer en SSH, rendez-vous à la fin de cette partie pour

apprendre le SSH.

Activation I2C

Pour commencer, il faut activer les ports I2C de la Raspberry Pi, cela nous permet de

communiquer avec le capteur laser. Pour cela, ouvrez un terminal de commande (ctrl+alt+t)

et entrez cette ligne de commande :

La fenêtre suivante s’ouvre :

Ce dernier objet se fixe sur le mors de

gauche (ci-dessus). Il permet de renvoyer

les ondes émises par le capteur de

mesure. Vous pouvez si vous le souhaiter

en fabrique un 2eme plus petit en

modifiant ses dimensions, pour le capteur

laser (VL53L0X). Le modèle fournis est

dimensionné pour être compatible avec le

capteur à ultrason (HC-SR04).

7


Dans Interface Options, activez I2C

Pour finir cliquez sur finish et redémarrez votre Raspberry pi

Installation de l’application

Nous voulons à présent récupérer le code de l’application créé pour ce projet. Pour cela

nous allons utiliser la commande git pour télécharger les fichiers contenant le code depuis

le site de GitHub.

1. Avant de l’installer, assurons-nous que les paquets de Linux sont à jour :
2. Téléchargeons le dossier SAE-pince-industrielle dans le répertoire principal
3. Nous n’avons pas besoin du dossier ressources, supprimons-le

Installation des modules

L’application utilise des modules pour faire tourner Pifacecad ou le capteur laser.

Pour le capteur nous allons utiliser un module créer par @johnbryanmoore (https://github.com/johnbryanmoore) sur GitHub. (https://github.com/johnbryanmoore/VL53L0X_rasp_python)

1. Assurons-nous tout d’abord que nous disposons des outils de Python nécessaires

8

2. Maintenant téléchargeons le module dans le répertoire python (qui contient le code de

l’application et qui a besoin de ce module) et compilons le module sur notre Raspi.


3. Installons le module Pifacecad (écrivez les 3 lignes sur une seule ligne)

Vous avez à présent bien installé le module Python pour le capteur Tof. Félicitation !

4. Regardons ce que nous avons dans le répertoire python présent

main.py est le programme à exécuter, appli.py contient la classe qui gère toute l’interface,

HCSR04.py et VL53L0X.py contiennent les classes qui gères les capteurs, manual.txt et

parameter.txt sont des fichiers texte indispensable au bon fonctionnement de appli.py

Votre Raspberry Pi est à présent prête pour lancer l’application ! Mais avant cela, il faut

assembler les cartes (SparqEE et Pifacecad) et bracher les câble breadboard.

Se connecter en SSH

Avant de vous lancer dans l’assemblage, voyons comment vous pourrez lancer l’application

sans brancher votre Raspberry Pi à un clavier ni à un écran. Nous allons utiliser la magie

d’internet avec le protocole SSH (Secure Shell) qui permet de communiquer en ligne de

commande d’un ordinateur à un autre via interne et de façon sécurisée. Pour que cela

fonctionne vous devez utiliser un ordinateur portable connecté au réseau wifi « uha » et

votre Raspberry Pi doit également être connecté au même réseau.

1. Sur la Raspberry répéter l’étape activation I2C mais au lieu d’activer l’I2C, activez le

SSH


2. Le protocole SSH nécessite l’adresse IP de l’ordinateur sur lequel on veut se

connecter. Récupérons l’adresse IP de notre Raspberry Pi

9

3. Sur votre ordinateur portable lancer un terminal et tapez ssh pi@[votre adresse ip]
4. Le mot de passe par défaut est raspberry pour des raisons de sécurité il est caché

lorsque vous le taper.

Vous êtes maintenant connectée en SSH à votre Raspberry Pi, bravo ! Retenez bien

l’adresse ip pour vos futurs connexion…

# ASSEMBLAGE

Pour chaque état, il peut y avoir des prérequis, comme une vis ou des outils. Vous pouvez

vous en procurez à l’IUT Lab. Lisez d’abord toute cette partie avant de commencer !

Etape 1 : Préparation du Raspi


Etape 2 : Fixation Raspi

Prérequis :

- Scotch d’électricien
- Pâte à fixe (non obligatoire)

Collez quelques couche (3 ou plus) de

scotch afin de prévenir d’éventuelles cours

circuit avec la carte SparqEE. Si vous avez

de la pâte à fixe, posez-en sur le port

Ethernet pour stabiliser la position de la

carte SparqEE.


Prérequis :

- x4 Vis M2.5 5mm
- Clé Torx

Visser les 4 vis dans les 4 trous disponible

de la Raspberry Pi. Ne serrez pas tout de

suite, visser d’abord un peu chaque vis,

puis serrer les une part une. Cela évite de

créer des tensions sur la carte.

10


Etape 3 : Soudure du SparqEE

Etape 4 : Connexion GPIO

Prérequis :

- Fer à souder + étain
- Câble breadboard
- Pince coupante

Prenez un câble de breadboard femelle et

couper son extrémité. Dénuder le câble.

Faite exactement les mêmes soudures que

sur la photo. Il est recommandé d’utiliser

les mêmes couleurs de câble.

Prérequis :

- Câble breadboard femelle /

femelle

Connecter des câbles sur les GPIO

du Raspberry Pi comme indiquer sur

le schéma. Comme précédemment

essayer | d’utiliser | des | couleurs

uniques par câble, pour ne pas vous

perdre par la suite.

11

Etape 5 : Fixation SparqEE

Fixer le SparqEE sur les pins GPIO de la

Raspberry Pi. Appuyez pour bien les fixer

entre eux. Faites attention à ce que tous les

câble passe par l’arrière.


Etape 6 : Pose boutons

Poser les 5 boutons dans leurs trous.

Attention, la partie plate doit être placé à

l’intérieur du boitier. Pour ne pas les faires

tomber, maintenez le boitier pencher.


Etape 7 : Fixation Pifacecad


Cette étape est délicate. Il faut arriver dans un

premier temps à fixer les pins du Pifacecad sans

toucher les boutons en plastique. Pour se faire

appliquer une tension vers l’avant des pins tout

en pressant vers le bas pour fixer les pins.

Relâcher pour déposer les boutons du Pifacecad

sur les boutons en plastique. Le tout en gardant

le boitier pencher.

12

Etape 8 : Placement câbles


Commencez par sélectionner un par un vos câbles

avec une main et stocker les dans votre seconde

main. Ensuite faites entrer le paquet de câble dans

la fente et placer un objet plat au-dessus du

couvercle pour maintenir le 12 câble plat.

Vous pouvez décider vous-mêmes du placement

des câbles, sinon placez-les comme sur le schéma.


Etape 9 : Coller câble


Prérequis :

- Pistolet à colle chaude

Astuce :

- Faites chauffer le pistolet avant l’étape 8

Tout en gardant l’objet plat sur le dessus du couvercle

pour maintenir les câbles plats, appliquez de la colle

chaude tout autour des câbles. Soufflez dessus pour

accélérer le processus de séchage. Continuer jusqu’à

que la colle ne soit plus transparente mais opaque.

Vous pouvez à présent fermer le couvercle et

contempler le boitier terminé !

13


Etape 10 : Fixation clips

Prérequis :

- Super glue

Attention : Avant de commencer assurez-vous que

les clips peuvent rentrer dans les encoches. Dans

le cas contraire modifier les dimensions des clips

et réimprimés les.

Introduisez quelques goûtes de super glue dans

les 4 encoches des 2 boitiers. Fixer les clips sur le

boitier de la batterie (attention à ne pas mettre de

colle sur vos doigts). Venez ensuite placer le

boitier de la Raspberry Pi sur l’autre boitier.

Appuyer fermement sur le dessus. Si cela ne

rentre pas, donner des coups.

Etape 11 : Liaison câble

Fig. 1 | Fig. 2 | Fig.3

### Fig. 4

14

Fig. 5; Fig. 6

Prérequis :

- Scotch
- Serflex (optionnel)
1. Commencer par connecter les 3 LEDs du PCB (fig.4) sur les sorties du boitier.
2. Brancher sur le boitier, les sorties (5V, Echo Trig) du capteur ultrason (HC_) sur la

partie Entrée du PCB (fig.4)

3. Brancher la masse du boitier à la masse Entrée du PCB.
4. Connecter sur le bornier du PCB la partie Sortie de HC avec des câbles dénudé /

femelles. Ils ne doivent pas être directement connecter au mors. Enrouler du scotch

sur la partie femelle comme sur la fig.2

5. Sur la fig.2 le paquet de câble en bas à droite représente la connexion HC Sortie du

PCB, il est relié par un paquet qui part vers le haut. Ce paquet arrive sur la fig.3 il est

connecté au mors. Comme vous pouvez le constater les couleurs sont identique pour

permettre une meilleure simplicité de connexion.

6. Connecter le capteur HC comme sur la fig.5 et vérifier que le circuit électrique est bien

branché de la sortie du boitier, à la connexion au capteur.

7. Remplacer le capteur ultrason par le capteur laser (fig.6). Débrancher les câbles

connecter entre le mors et le PCB (comme sur la fig.2)

8. Prenez 4 câble mâle / femelle avec des couleurs similaires (paquet gauche de la fig.2)

et connecter les aux câbles du mors. Maintenant en partant d’une connexion du

capteur, suivez le câble et connecter le directement au boitier.

9. La masse est déjà utilisé sur le boitier, connecter là plus tôt sur le PCB (masse Entrée)

10.Les 2 dernières connexion (bit1, bit2) servent à chiffrer le signal d’état au robot.

Demander au professeur si vous voulez les utiliser pour qu’ils vous expliquent.

11.Vos connexions finies devraient ressembler à la fig.1 Ajouter si vous voulez des serflex

pour plus de d’ergonomie.

15

Etape 12 : Fixation plaque


Etape 13 : Fixation mors


# UTILISATION DE L’INTERFACE

Maintenant que la partie technique et informatique est bien réglé, vous pouvez utiliser

l’interface utilisateur de l’application.

Lancement de l’application

Pour commencer alimenter la Raspberry Pi par la batterie externe via le câble micro USB.

Attendez quelques secondes que le système d’exploitation démarre et qu’il se connecte

automatiquement au réseau wifi « uha ». Connecter vous en SSH avec votre ordinateur

portable. Dans une console exécutez le programme après vous être déplacer dans le bon

dossier.

Prérequis :

- x6 vis M3 16mm
- Clé Torx
- Déplacer le bras du robot vers le sol

Commencer par visser le PCB sur la pince.

Placer au préalable un petit papier entre la

pince et le PCB pour éviter les courts-

circuits. Ne serrez pas trop fort. Ensuite

visser chaque mors avec 2 vis comme sur

la photo. Serrez fort.

Prérequis :

- x2 vis M2
- Tournevis plat

Avec le tournevis reproduisez la fixation

comme sur la photo. Si la vis ne rentre pas,

grattez les trous avec une pince coupante

pointu par exemple.

16

L’écran LCD devrait s’allumer et afficher ceci

Pour entrer dans un menu :

- Déplacez-vous avec les boutons curseur avance et curseur recule puis appuyez sur

le bouton valider pour charger le menu.

Pour revenir sur l’écran d’accueil :

- Sélectionner OK avec le curseur puis appuyez sur valider
- Appuyez sur le bouton retour accueil

Prendre une mesure (get)

Déplacer le curseur sur get avec le curseur puis avec le bouton valider vous déclenchez la

mesure du capteur, entrainant le chiffrement de l’état qui va s’actualiser sur l’écran LCD, les

LEDs du PCB, et le robot.

Définir limite état (set)

L’état de la pince est défini par les limites min

et max. On peut résumer le fonctionnement

de la gestion de l’état avec un organigramme.

Sur la configuration on peut donc dire que la

pince est détecté ouverte si la distance est

strictement supérieure à 20cm, fermée si la

distance est strictement inférieure à 10cm et

en prise si la distance est comprise dans les

l’intervalle [10cm, 20cm].

Changer les valeurs des limites :


1. Sélectionner min ou max avec le curseur, appuyez sur valider
2. Déplacez-vous sur le chiffre à modifier avec le curseur. Appuyez sur valider
3. Défilez le chiffre avec le curseur
4. Lorsque vous avez fini, cliquez sur

« * » pour sortir de la sélection

Réinitialisé les valeurs par défaut

1. Sélectionner rs puis appuyez sur valider

17

Mode de mesure (mod)

Le mode actuellement sélectionner

est représenter par la petite étoile

« * ».

Mode manuel :

- L’utilisateur doit appuyez sur get de l’écran d’accueil pour faire une mesure.
- Ce mode est utile pour paramétrer set

Mode auto :

- La raspberry Pi envoie une demande de mesure toute les x secondes. La variable x

est définie en fonction de la précision du capteur (voir Type de précision)

Type de précision (typ)

Les 2 capteurs ont différents

type/mode | de | mesure. | Speed

permet d’avoir une très grande

réactivité de changement d’état

grâce à une fréquence élevé de mesure, mais au détriment de la précision de chaque

mesure. Tandis que beter fait l’inverse. Voyons les caractéristiques de chaque mode.

Capteur LASER | Fréquence de mesure | Delta d’erreur
speed | 50/s | ± 6mm
good | 30/s | ± 4mm
better | 15/s | ± 2mm
best | 5/s | ± 1mm
Capteur ULTRASON | Fréquence de mesure | Delta d’erreur
speed | 60/s | ± 30mm
good | 35/s | ± 5mm
better | 20/s | ± 4mm
best | 8/s | ± 3mm

Si vous voulez un système très rapide et instantané dans la détection de changement d’état

préférez un mode se rapprochant de speed.

Si vous préférez un système qui ne fait jamais d’erreur de d’état, préférez un mode se

rapprochant de best.

18

Changer de capteur (cap)

Dans ce menu vous pouvez

changer physiquement le capteur

qui permet de réaliser les mesures.

Dès l’entré dans ce menu, le mode

de | mesure | manual | s’active

instantanément pour pouvoir changer sans erreur le capteur.

Changer un capteur :

1. Sélectionner le nouveau capteur (n’appuyez pas sur valider)
2. Débranchez le capteur actuel
3. Débrancher les câbles mâles du mors
4. Bracher le nouveau capteur sur le mors
5. Appuyez sur le bouton valider

Menu Help (H)

Le menu Help permet d’avoir accès

à un court manuel d’utilisation de

chaque menu disponible sur l’écran

d’accueil. Sur la droite l’affichage

des mesures est remplacé par exit qui permet de quitter proprement le programme. Vous

pouvez aussi appuyer sur le premier bouton Quitter pour effectuer la même action.

Lire le manuel d’un menu :

- Sélectionner avec le curseur le menu souhaiter
- Appuyez sur le bouton valider
- Le texte du manuel s’affiche sur l’écran. Pour faire défiler le texte, utiliser les boutons

avance et recule.

- Lorsque vous avez fini de lire, appuyez simplement sur le bouton valider pour revenir

sur le menu Help

19

# FOIRE AUX QUESTIONS

Vous avez un problème ? Vous avez des questions ? Vous êtes au bon endroit !

Puis-je utiliser ce projet pour simplement tester les capteurs ?
- Bien sûr, vous n’êtes pas d’ailleurs obligé de réaliser les impression 3D. Uniquement

les modules SparqEE et Pifacecad sont nécessaires au bon fonctionnement. Le PCB

peut aussi être simplifié en un montage sur une breadboard.

J’ai bien suivi les étapes de la construction mais l’application ne fonctionne pas.
- Suivez le circuit que parcourt chaque câble et vérifier que si le circuit arrive bien au

bon endroit.
- Démontez tout et recommencer tout :) Généralement c’est une technique qui marche

Lorsque je lance le programme, une erreur se produit.
- Vérifiez que vous avez bien installer les modules
- Si l’erreur se termine par « No such file or directory » cela signifie que vos répertoires

sont mal rangés, ou que vous avez déplacé/renommé un fichier. Supprimez le

répertoire SAE-pince-industrielle et recommencer la partie installation du programme
- Si l’erreur n’est pas celle-là, vérifier que vos ports I2C sont bien activés, et que le

Pifacecad est bien braché.

Les mesures que j’obtient ne sont pas juste
- Il est fortement probable que votre capteur soit endommagé, essayer de vérifier avec

un autre capteur. Mais avant de le faire revérifier les branchements encore une fois.

# Projet fait avec <3

Pour les étudiants,

Par les étudiants.

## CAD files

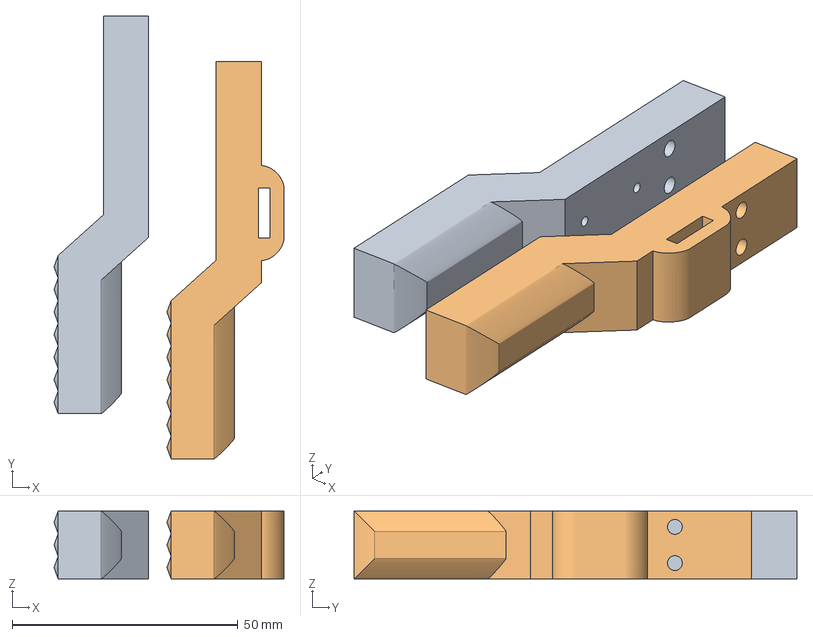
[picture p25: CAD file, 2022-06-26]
ressources/model-3D/Fichier 3MF/paire_mors.3mf
50.9 x 98.0 x 15.0 mm
Corps1 x 2

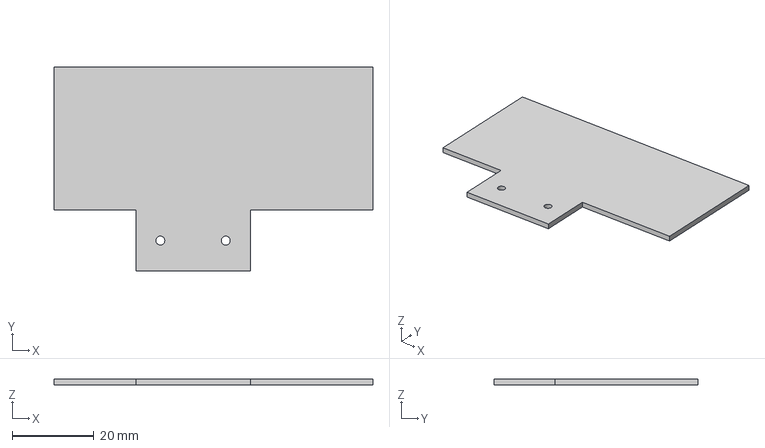
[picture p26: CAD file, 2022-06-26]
ressources/model-3D/Fichier 3MF/plaque.3mf
78.0 x 50.0 x 1.50 mm

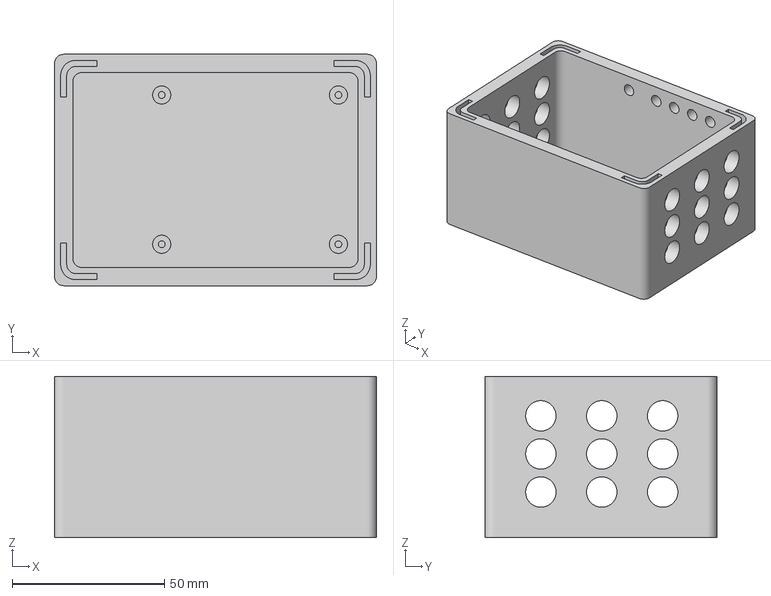
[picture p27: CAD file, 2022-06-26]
ressources/model-3D/Fichier 3MF/boitier_raspi.3mf
105.7 x 76.0 x 53.0 mm

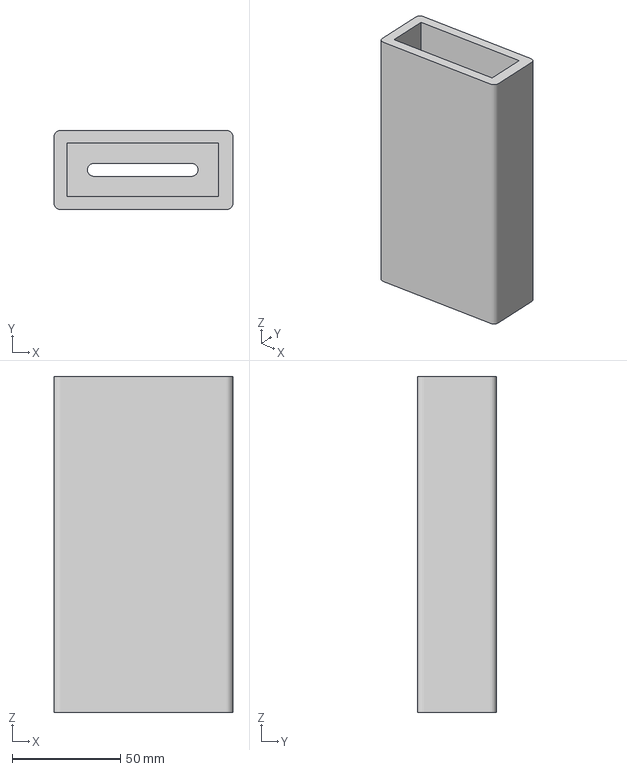
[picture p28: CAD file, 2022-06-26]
ressources/model-3D/Fichier 3MF/boitier_batterie.3mf
82.5 x 36.5 x 154.9 mm

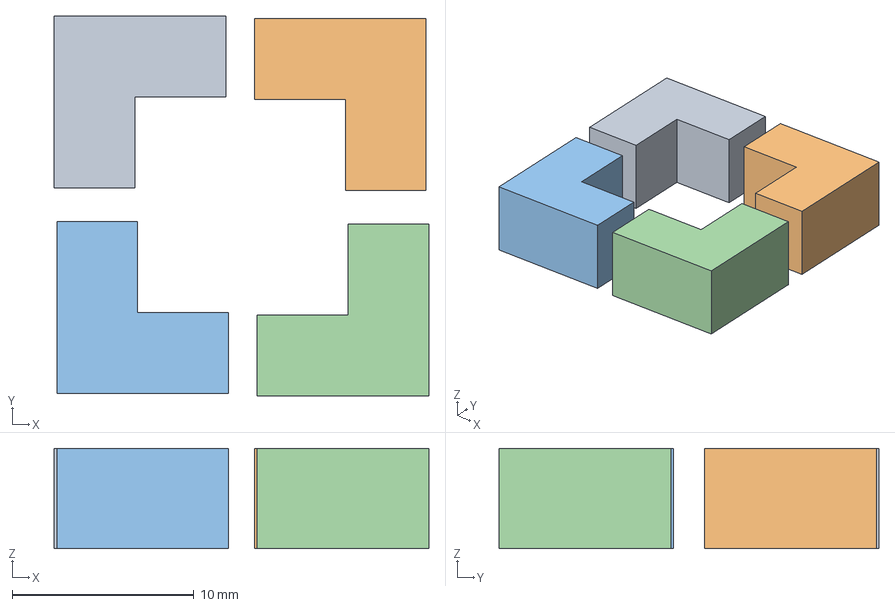
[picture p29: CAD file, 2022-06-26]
ressources/model-3D/Fichier 3MF/clips.3mf
20.6 x 20.9 x 5.50 mm
Corps1
Corps2
Corps3
Corps4

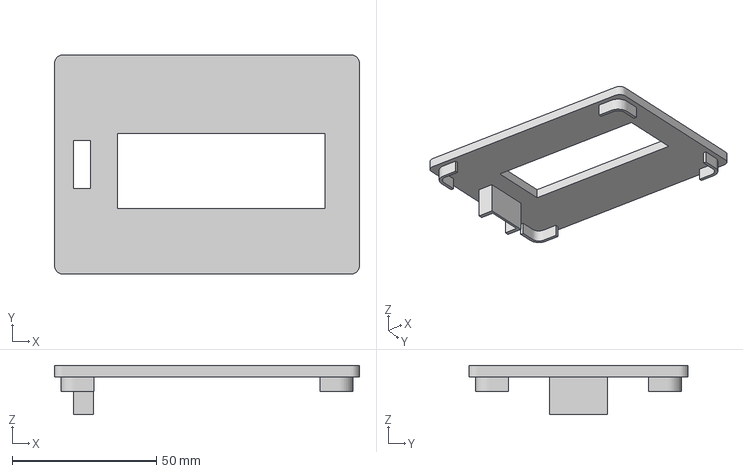
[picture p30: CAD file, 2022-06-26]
ressources/model-3D/Fichier 3MF/couvercle.3mf
105.7 x 76.0 x 17.0 mm

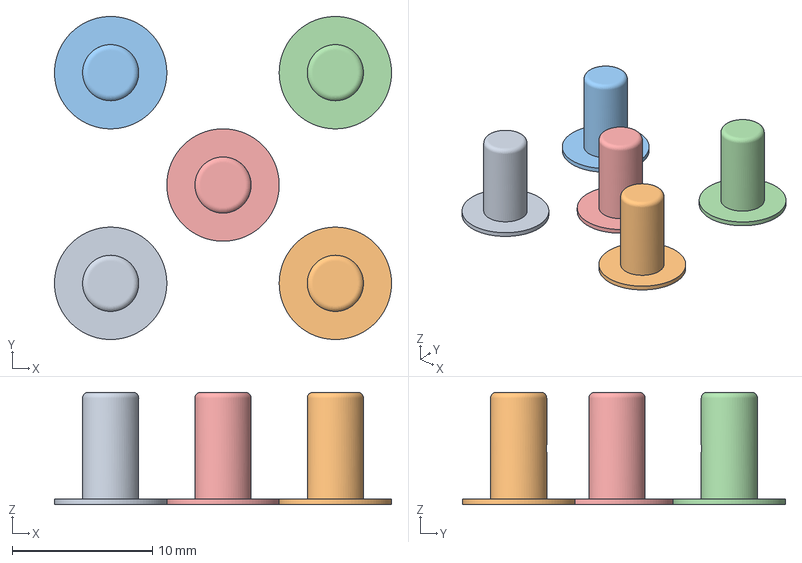
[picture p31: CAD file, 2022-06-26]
ressources/model-3D/Fichier 3MF/boutons.3mf
24.0 x 23.0 x 8.00 mm
Corps1
Corps2
Corps3
Corps4
Corps5

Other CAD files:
ressources/model-3D/Fichier Fusion/boitier_batterie.f3d
ressources/model-3D/Fichier Fusion/boitier_raspi.f3d
ressources/model-3D/Fichier Fusion/boutons.f3d
ressources/model-3D/Fichier Fusion/clips.f3d
ressources/model-3D/Fichier Fusion/couvercle.f3d
ressources/model-3D/Fichier Fusion/mors_droit.f3d
ressources/model-3D/Fichier Fusion/mors_gauche.f3d
ressources/model-3D/Fichier Fusion/plaque.f3d

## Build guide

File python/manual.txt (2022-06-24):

get:
Validez pour prendre une mesure via le capteur Tof. Cette mesure sera affichee sur l'ecran lcd en haut a droite en mm, puis chiffree dans 1 des 3 etats de la pince ouvert=ope, ferme=clos, prise=tak avant d'etre retranscrit sur l'ecran lcd en bas a gauche et sur une LED.

set:
Menu set. Definir les bornes de mesure min et max pour parametrer le chiffrage de l'etat de la pince: mesure < min -> ferme, mesure > max -> ouvert, sinon -> prise

H:
Menu help. Affiche le manuel d'utilisation de chaque menu. Exit permet de quitter proprmenet le programme et de sauvegarder les parametres (set, led).

mod:
Menu mode. Choisir le mode de mesure manuel ou automatique. auto=boucle infini: prendre une mesure, afficher la mesure et l'etat de la pince, attendre un delais definie par le type de mesure.

typ:
Menu type. Choisir la qualite des mesures du capteur Tof ce qui a pour effet d'influe sur le temps de pause entre chaque mesure. good=34ms better=66ms best=200ms long=34ms speed=20ms

cap:
Menu capteur. Pour changer de capteur selectionner votre capteur. Enelver le capteur actuelle. Fixer le nouveau capteur selctionner.

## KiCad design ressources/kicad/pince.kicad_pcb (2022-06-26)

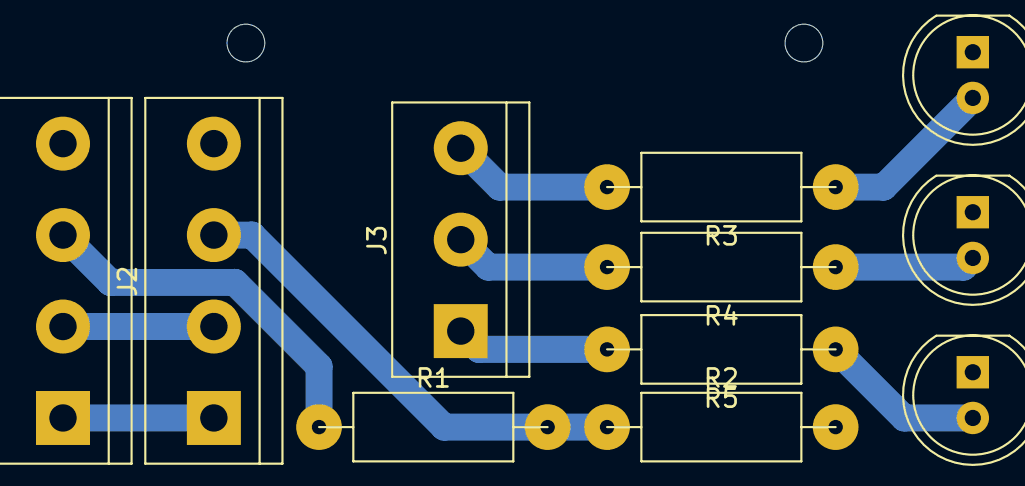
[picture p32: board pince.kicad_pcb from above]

Board: 2 copper layers, 11 parts (0 on the bottom side), 11 nets.

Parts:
D1, D2, D3: LED; LED_D8.0_mm_mod
J1, J2: Screw_Terminal_01x04; TerminalBlock_bornier-4_P5.08mm
J3: Screw_Terminal_01x03; TerminalBlock_bornier-3_P5.08mm
R1: 1000; R
R2: 2000; R
R3, R4, R5: R

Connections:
Earth: D1.1, D2.1, D3.1, J1.4, J2.4, R2.2
unnamed: D1.2, R3.1
unnamed: D2.2, R4.1
unnamed: D3.2, R5.1
unnamed: J1.1, J2.1
unnamed: J1.2, J2.2
unnamed: J1.3, R1.1
unnamed: J2.3, R1.2, R2.1
unnamed: J3.1, R5.2
unnamed: J3.2, R4.2
unnamed: J3.3, R3.2

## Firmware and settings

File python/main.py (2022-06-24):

#!/usr/bin/python3
import asyncio, pifacecad
import RPi.GPIO as GPIO
from appli import Application

cad = pifacecad.PiFaceCAD()
app = Application(cad)

async def update_buttons():
    pin_buttons = [0, 1, 2, 3, 4]
    buttons = [0]*len(pin_buttons)
    old_buttons = buttons[:]
    while 1:
        buttons = [cad.switches[pin].value for pin in pin_buttons]
        if buttons != old_buttons and sum(buttons):
            if buttons[4]:
                app.action_enter()
            elif buttons[3]:
                app.action_cursor(sens=1)
            elif buttons[2]:
                app.action_cursor(sens=-1)
            else:
                app.action_button(buttons.index(1))
            await asyncio.sleep(0.1)
        old_buttons = buttons[:]
        await asyncio.sleep(0.01)

async def update_mesure():
    while 1:
        if app.parameter["mod"]=="auto":
            app.get_mesure()
            app.update_led()
            app.update_optoc()
        await asyncio.sleep(app.delay)

async def update_lcd():
    while 1:
        if app.parameter["mod"]=="auto" and app.id_menu=="home": 
            app.update_mesure()
        await asyncio.sleep(0.5)

async def main():
    # Schedule three calls *concurrently*:
    await asyncio.gather(update_buttons(), update_mesure(), update_lcd())

asyncio.run(main())

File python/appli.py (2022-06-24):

import RPi.GPIO as GPIO
from VL53L0X import CapteurTof
from HCSR04 import CapteurHC
from os import system

# Féfinition de la classe Application
class Application(object):
    """Classe qui contrôle chaque menuu de l'application"""
    def __init__(self, cad):
        # Configuration du pifacecad
        self.cad = cad
        self.cad.lcd.backlight_on()
        self.cad.lcd.blink_off()
        self.cad.lcd.cursor_off()
        # Gestion mesure et chiffrage
        self.mesure = 0
        self.etat = "ope"
        self.led_color="green"
        # coordonnées de départ et des menus
        self.cursor = 0
        self.col, self.row = (0,0)
        self.id_menu = "home"
        self.db_menu = {
            'home':[("get",(1,0)),("set",(5,0)),("H",(9,0)),("mod",(1,1)),("typ",(5,1)),("cap",(9,1))],
            'typ': [("good",(1,0)),("beter",(6,0)),("best",(1,1)),("speed",(6,1)),("OK",(14,1))],
            'set': [("min:",(1,0)),("max:",(1,1)),("rs",(14,0)),("OK",(14,1))],
            'mod': [("auto",(1,0)),("manual",(1,1)),("OK",(14,1))],
            'cap': [("laser",(1,0)),("ultrason",(1,1)),("OK",(14,1))],
            'H':   [("get",(1,0)),("set",(5,0)),("H",(9,0)),("mod",(1,1)),("typ",(5,1)),("cap",(9,1)),("exit",(12,0)),("OK",(14,1))]
        }
        # Récupération des parametres enregistrés dans le fichier texte
        f = open("parameter.txt", 'r')
        self.parameter = eval(f.readline())
        self.led_pin = eval(f.readline())
        self.optoc_pin = eval(f.readline())
        self.optoc_etat = [0, 0]
        self.hc_pin = eval(f.readline())
        f.close()
        if self.parameter["cap"]=="laser":
            self.range = self.parameter["range_tof"]
        else:
            self.range = self.parameter["range_hc"]
        GPIO.setmode(GPIO.BCM)
        for pin in self.led_pin.values():
            GPIO.setup(pin, GPIO.OUT)
            GPIO.output(pin, 0)
        for pin in self.optoc_pin.values():
            GPIO.setup(pin, GPIO.OUT)
        # Récupération du manuel d'utilisation pour le menu Help
        f = open("manual.txt", 'r')
        brut = f.readlines()
        f.close()
        self.doc = {}
        self.doc_range = [0]*2
        for i in range(0, len(brut), 3):
            self.doc[brut[i][:-2]] = brut[i+1][:-1]
        # Gestion du menu set
        self.input_value = [0]*4
        self.input_lock = 0
        # Création d'un objet CapteurTof 
        self.tof = CapteurTof()
        # Création d'un objet CapteurHC
        self.hc = CapteurHC(self.hc_pin)
        if self.parameter["cap"]=="laser":
            self.tof.start_ranging(self.parameter["typ"])
            self.delay = self.tof.get_timing()
        else:
            self.delay = self.hc.get_timing(self.parameter["typ"])
        # Affichage du menu home
        self.update_model()
        #self.get_mesure()
        self.parameter["mod"] = "manual"
        self.update_mesure()
    def update_model(self):
        self.cad.lcd.clear()
        for element in self.db_menu[self.id_menu]:
            col,row=element[1]
            self.cad.lcd.set_cursor(col,row)
            self.cad.lcd.write(element[0])
        self.col, self.row = (1,0)
        self.cursor = 0
        self.update_selected()
        self.cad.lcd.home()
        self.cad.lcd.write(">")
    def change_captor(self):
        self.parameter["mod"]="manual"
        if self.parameter["cap"]=="laser":
                self.parameter["range_hc"] = self.range
                self.range = self.parameter["range_tof"]
                self.tof.start_ranging(self.parameter["typ"])
                self.delay = self.tof.get_timing()
        else:
            self.parameter["range_tof"] = self.range
            self.range = self.parameter["range_hc"]
            #self.tof.stop_ranging()
            self.delay = self.hc.get_timing(self.parameter["typ"])
    def input_set(self):
        row = self.cad.lcd.get_cursor()[1]
        self.cad.lcd.set_cursor(5, row)
        val=self.range[row]
        self.input_value = [val//1000%10]+[val//100%10]+[val//10%10]+[val%10]
        self.cad.lcd.write("0"*(4-len(str(val)))+str(val)+"mm*")
        self.cad.lcd.set_cursor(5, row)
        self.cad.lcd.cursor_on()
    def input_update(self, sens):
        if sens==0:
            if self.input_lock:
                self.cad.lcd.blink_off()
                self.input_lock=False
            elif self.cad.lcd.get_cursor()[0]==11:
                newValue = 0
                self.input_value.reverse()
                for i in range(4):
                    newValue+=10**i*self.input_value[i]
                self.range[self.row] = newValue
                self.id_menu="set"
                self.cad.lcd.cursor_off()
                self.cad.lcd.blink_off()
                self.update_set()
            else:
                self.cad.lcd.blink_on()
                self.input_lock=True
        elif self.input_lock:
            col = self.cad.lcd.get_cursor()[0]-5
            self.input_value[col]+=sens
            if self.input_value[col]<0:
                self.input_value[col] = 9
            elif self.input_value[col]>9:
                self.input_value[col] = 0
            self.cad.lcd.write(str(self.input_value[col]))
            self.cad.lcd.set_cursor(col+5, self.row)
        else:
            col, row = self.cad.lcd.get_cursor()
            col += sens
            if col<5:
                col=5
            elif col==10:
                col=8
            elif col>8:
                col=11
            self.cad.lcd.set_cursor(col, row)     
    def update_set(self):
        range_str = ['']*2
        for i, val in enumerate(self.range):
            range_str[i] = "0"*(4-len(str(val)))+str(val)+"mm "
        for k in range(2):
            self.cad.lcd.set_cursor(5,k)
            self.cad.lcd.write(range_str[k])
        self.cad.lcd.set_cursor(self.col, self.row) 
    def get_mesure(self):
        if self.parameter["cap"]=="laser":
            self.mesure = self.tof.get_distance()
        else:
            self.mesure = self.hc.get_distance()
        if self.mesure > 8000 or self.mesure < 0:
            self.optoc_etat = [1, 1]
            self.led_color = "Error"
            self.etat = "err"
        elif self.mesure > self.range[1]:
            self.etat = "ope"
            self.led_color = "green"
            self.optoc_etat = [1, 0]
        elif self.mesure < self.range[0]:
            self.etat = "clo"
            self.led_color = "red"
            self.optoc_etat = [0, 1]
        else:
            self.etat = "tak"
            self.led_color = "orang"
            self.optoc_etat = [0, 0]
            #print(self.optoc_etat)
    def update_mesure(self):
        if self.mesure > 8000 or self.mesure<0:
            ch_mesure = "out"
        else:
            ch_mesure = str(self.mesure)
        self.cad.lcd.set_cursor(10, 0)
        self.cad.lcd.write(' '*(4-len(ch_mesure))+ch_mesure+"mm")
        self.cad.lcd.set_cursor(13, 1)
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

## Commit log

2022-06-24 fichiers du projet actuelle
    Ces fichiers ne comprennent pas les commentaires et sont encore corrigeables
    [parameter.txt]
2022-06-24 séparation en dossier
    [parameter.txt]
2022-06-24 ajout d'un fichier 3D
    [boitier_raspi.3mf]
2022-06-24 nouveau dossier
    [boitier_raspi.3mf]
2022-06-25 ajout de kicad et du manuel d'utilisation
    [pince.kicad_pcb, pince.sch]
2022-06-26 supprime fichier temp kicad
2022-06-26 ajout des fichiers 3D
    [boitier_raspi.3mf]
2022-06-26 fichiers 3D
    [boitier_batterie.3mf, boitier_batterie.f3d, boitier_raspi.3mf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]
